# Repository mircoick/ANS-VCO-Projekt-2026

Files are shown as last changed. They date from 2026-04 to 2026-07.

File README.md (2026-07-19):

17.07.2026

<div align="center">

# VCO Design und Simulation

**Entwicklung und Inbetriebnahme eines Wien-Robinson-Oszillators als
Voltage-Controlled-Ozillator ($f_0=5,5~\text{MHz}$)**






<table style="border: none; border-collapse: collapse; margin: 0 auto;" border="0">

<tr style="border: none;">

<td style="border: none; padding: 0 25px; text-align: center;">

Tassilo Hertling


</td>

<td style="border: none; padding: 0 25px; text-align: center;">

Torben Becker


</td>

<td style="border: none; padding: 0 25px; text-align: center;">

Mirco Ick


</td>

</tr>

</table>

</br> </br>

**Dateiübersicht**

[KiCad-Dateien](kicad/) · [Simulationsdaten](sim/) · [Python
Code](code/) · [Datenblätter](datasheets/)

</div>

------------------------------------------------------------------------

# Einleitung

In diesem Projekt gilt es einen VCO (Voltage Controlled Oszillator) zu
designen und in Betrieb zu nehmen. Das Design soll bestimmte
Anforderungen erfüllen, damit es in einem Laborversuch als FM-Modulator
genutzt werden kann. In der Vergangenheit wurde im Laborversuch eine VCO
Schaltung mit alten und abgekündigkten Komponenten verwendet. Diese
Schaltung soll nun mit neuen und verfügbaren Komponenten erneuert
werden.

Die VCO Schaltung soll eine FM-Modulation mit einem Trägersignal bei der
Frequenz $5,5~\text{MHz}$ durchführen und einen Modulationsbereich
zwischen $5~\text{MHz}$ und $6~\text{MHz}$ verwenden. Der
Einstellungsbereich soll mit $1~\text{V}$ pro $1~\text{MHz}$ eingestellt
werden. Somit kann das zu modulierende Signal einen Spannungsbereich von
$V_{pp} = 1~\text{V}$ haben. Die Ein- und Ausgangsimpedanz soll
$50~\Omega$ betragen.

Zudem soll die Schaltung aus Komponenten bestehen, die Studierenden im
4.Semester bereits kennen, damit die Schaltung im Rahmen des
Laborversuchs im Grunde verstanden werden kann. Aus dieser
Rahmenbedingung folgt die Auswahl der spezifischen VCO-Schaltung.

Die Platine soll zudem relativ groß ausgelegt werden und es sollen
möglichst bedrahtete Bauteile verwendet werden. In dem Laborversuch soll
ebenfalls die Kennlinie des FM-Modulators aufgenommen werden. Hierfür
ist ein integrierter einstellbarer Spannungsteiler vorgesehen, der über
einen Drehregler auf der Platine eingestellt werden soll.

Die Schaltung soll ebenfalls Stabil gegenüber Schwankungen in der
Versorgungsspannung und somit in der Ausgangsfrequenz ausgelegt sein.
Anschlüsse für die im Laborversuch verwendeten Geräte wie das
Oszilloskop und dem Spektrumanalysator sollen über SMA- oder
BNC-Anschlüsse geschehen.

# Technische Spezifikationen (Kundenanforderungen)

- **Mittenfrequenz ($f_0$):** $5,5~\text{MHz}$ (Zwischenfrequenz / ZF)
  bei einer Steuerspannung von $0~\text{V}$.

- **Linearer Modulationsbereich:** $\pm 0,5~\text{MHz}$ (Frequenzhub)
  bei einer Steuerspannung von $\pm 0,5~\text{V}$.

  - *Arbeitsbereich:* $5,0~\text{MHz}$ bis $6,0~\text{MHz}$ linear im
    Spannungsbereich von $-0,5~\text{V}$ bis $+0,5~\text{V}$.

- **Frequenzstabilität:** Es darf keine Frequenzverschiebung (Drift)
  durch thermische oder externe Einflüsse auftreten.

- **Systemimpedanz:** Ein- und Ausgangswiderstand müssen exakt
  $50~\Omega$ betragen.

- **Steckverbinder:** Ein- und Ausgänge sind als **SMA-** oder
  **BNC-Buchsen** auszuführen.

- **Schaltungsarchitektur:** Einfacher, leicht zu verstehender und
  nachvollziehbarer Aufbau (diskreter Bauelemente).

- **Spannungsversorgung:** Integrierte Stabilisierung und Filterung der
  Versorgungsspannung zur Rauschunterdrückung.

- **Manuelle Steuerung:** Integrierter Spannungsteiler mit einem
  analogen Drehknopf (Potentiometer) zur Frequenzeinstellung.

- **Platinedesign:** Relativ große, robuste und mechanisch
  unempfindliche Leiterplatte.

- **Bestückungstechnologie:** Ausschließlich **stehende, bedrahtete
  Bauteile** für optimale Zugänglichkeit (keine SMD-Bauteile).

# Designverlauf

## Grundlegender VCO

Zuerst wurde im Design angefangen ein passendes VCO-Modell nach den
Anforderungen auszusuchen. Als Modell haben wurde sich für den LC-VCO
entschieden. Dieser besteht im Grunde aus einer RLC-Schaltung und einer
kreuzgekoppelten Mosfet-Schaltung. Das Design ist somit gut für
Studierende aus dem 4. Semester zu verstehen und kann auch gut mit
bedrahteten Bauteilen aufgebaut werden. Die Grundschaltung ist in
<a href="#fig-circuit" class="quarto-xref">Abbildung 1</a> zu sehen:

<div id="fig-circuit">

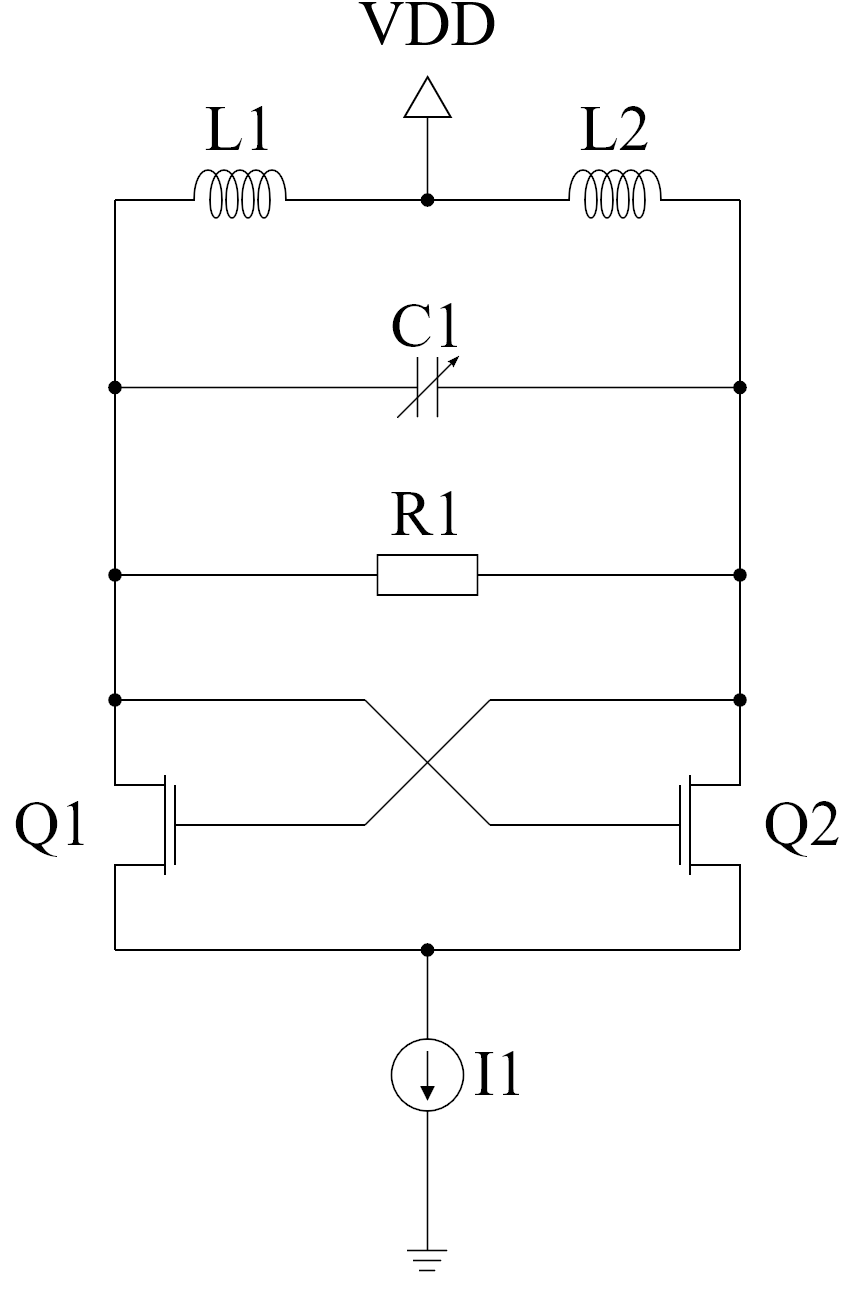
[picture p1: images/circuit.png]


Abbildung 1: VCO-Grundschaltung

</div>

In der Grundschaltung sind im oberen Bereich die beiden Induktivitäten
$L1$ und $L2$ in doppelter Ausführung zu sehen, da die
Versorgungsspannung mittig angeschlossen werden muss, um die Symmetrie
der Schaltung gewärleisten zu können. Weiter unten ist der einstellbare
Kondensator $C1$ zu sehen, dessen Wert die Schwingung der Schaltung
maßgeblich beeinflusst. Durch die Änderung des Kondensator ändert sich
auch die Frequenz $f_0$ der Schaltung. Somit kann duch eine gesteuerte
Änderung der Kapazität die Frequenz der Schwingung eingestellt werden.
Das ist das Grundprinzip des VCO´s und die Funktionsweise der
FM-Modulation. Der Widerstand $R1$ vervollständigt den RLC-Schwingkreis.
Die beiden kreugekoppelten Mosfets sind für die ständige Anregung der
Schwingung zuständig. Durch die ständige Änderung der gesamt Impedanz
des Schwingkreises ändert sich jeweils der Strom, der durch die Mosfets
am Gate Eingang anliegt. Diese Änderung bewirkt eine Rückgekoppelte
Schleife, durch welche schwingt das System dauerhaft. Nach
Implementierung dieser Schaltung in KiCad, NG- sowie LT-Spice konnte die
Funktionsweise sowie das Einstellen der Frequenz $f_0$ klarer gemacht
werden.

Im Verlauf der Entwicklung wurde sich entschieden verschiede VCO Ansätze
zu entwerfen und am Ende dem Kunden zu präsentieren. Unter den drei
Gruppen konnte sich neben dem Grund-VCO, welcher oben bereits erklärt
wurde, der Colpitts Oszillator oder der Wien-Robinson-Oszillator
ausgesucht werden. Da sich bereits im zweiten Semester ausgiebig mit der
Wien-Robinson Brücke auseinander gesetzt wurde haben wir uns für diesen
VCO entschieden, auf welchen in den nachfolgenden Kapiteln näher
eingegangen wird.

Eine Simulationsdatei ist dem Ordner
[VCO-Schwingkreis](kicad/Archiv/VCO-Schwingkreis/) zu entnehmen.

## Wien-Robinson-Oszillator

Um den Wien-Robinson-Oszillator besser verstehen zu können wurde sich
als erstes die Grundschaltung, die Wien-Robinson-Brücke, nochmals
angeschaut. Hierbei handelt es sich um eine frequenzabhängige
Wechselstrom-Messbrücke, die als sogenannte Nullbrücke konzipiert ist.
Das bedeutet, dass die Differenzspannung in der Brückendiagonale bei
einer spezifischen Resonanzfrequenz exakt
$\underset{\scriptscriptstyle\sim}{U} = 0~\text{V}$ beträgt. Ein
Schaltung ist der
<a href="#fig-wienrobbruecke" class="quarto-xref">Abbildung 2</a> zu
entnehmen.

<div id="fig-wienrobbruecke">

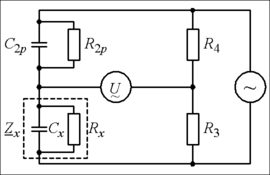
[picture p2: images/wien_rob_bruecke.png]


Abbildung 2: Wien-Robinson-Brücke
(<span class="nocase">de-academic.com</span> 2000-2026)

</div>

Wenn man nun an diese Brückendiagonale einen Operationsverstärker (OPV)
einbaut, erhält man einen aktiven Oszillator, der die
Frequenzselektivität der Brücke nutzt. Da der OPV die verschwindend
geringe Differenzspannung im Bereich der Resonanzfrequenz extrem hoch
verstärkt, reicht bereits das thermische Rauschen der Bauteile aus, um
das System resonant anzuregen. Somit erhält man einen sich selber
anwingenden Oszillator. Diese Wien-Robinson-Oszillator Schaltung ist
eine der meistgenutzen Schaltungen einer Wien-Robinson-Brücke und bietet
somit eine gute Grundlage des VCO’s. Für die ersten Tests mit dem
Wien-Robinson-Oszillator wurde die Seite des Elektroniktutors
herangezogen und versucht, die entsprechende Schaltung nachzustellen
(Mietke 2002-2026).

<div id="fig-wien">

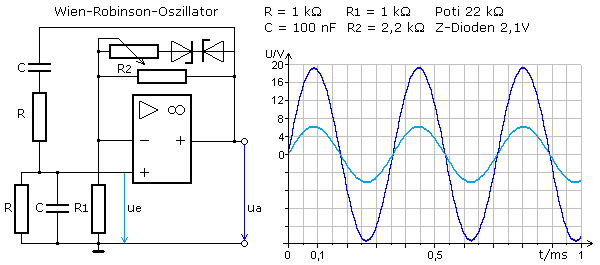
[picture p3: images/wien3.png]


Abbildung 3: Wien-Robinson-Oszillator Schaltung (Mietke 2002-2026)

</div>

Die in <a href="#fig-wien" class="quarto-xref">Abbildung 3</a> zu
sehende Schaltung zeigt wie bereits erörtert den in der
Brückendiagonalen eingebaute Operationsverstärker und eine zusätzliche
Amplitudenregulierung. Durch die starke Anregung der Schwingung des
OPV’s wurde hier noch eine Amplitudenregelung eingebaut, welche aus
einem Potentiometer und zwei entgegengeschalteten Varktordioden besteht.
Ohne diese Amplitudenregelung würde die Schwingung aufgrund der
unendlichen Verstärkung des OPV schnell bis an die Grenzen der
Versorgungsspannung anwachsen und begrenzen, was zu starken Verzerrungen
des Sinussignals führen würde. Die Regelung sorgt dafür, dass sich ein
stabiler, verzerrungsfreier Dauerschwingzustand einstellt.

Nachdem nun diese Schaltung erfolgreich in KiCAD, erst auf der
ursprünglichen Resonanzfrequenz $f_0=1592~\text{Hz}$ und anschließend
mit Änderung des OPV’s (LT7171) auf die gewünschten $5,5~\text{MHz}$,
umgesetzt wurde, konnte sich um den geforderten Frequenzhub von
$\Delta f=1~\text{MHz}$ bei einer Steuerspannungsänderung von
$U_{str}=\pm 0,5~\text{V}$ gemacht werden. Für den ersten Entwurf wurden
nun Varaktoren parallel zu den beiden Kondensatoren $C$ geschaltet.

Nach umsetzen dieser Schaltung haben sich jedoch zwei Probleme
kristallisiert. Zum einen kamen in den verschiedenen Simulationen (KiCAD
bzw. NG-Spice und LT-Spice) unterschiede Ergebnisse heraus, und zum
anderen war es nicht möglich die Kennlinie der Resonanzfrequenz $f_0$
über die Steuerspannung $U_{str}$ linear zu bekommen. Nach vielen
vergeblichen Versuchen wurde sich dann dazu entschieden den kompletten
Aufbau neu aufzusetzen und eine andere Schaltung zu verwenden.

## Wien-Robinson VCO

Die nachfolgende Schaltung in
<a href="#fig-wien-vco" class="quarto-xref">Abbildung 4</a> ist die
verwendete Schaltung für den Wie-Brücken-VCO. Am Anfang auf der linken
Seite ist die Verstärkerschaltung für die Steuerspannung der
Varaktordioden zu sehen. Diese soll die Einstellmöglichkeit für einen
Spannungsbereich zwischen $0~\text{V}$ und $1~\text{V}$ ermöglichen.
Diese Spannung geht über einen Widerstand auf die jeweiligen Kathoden
der Varaktordioden. Diese ändern ihre Kapazität in Abhängigkeit der
Steuerspannung. Der paralelle Kondensator ist hierbei für einen Offset
der Frequenz eingebaut worden und ist Teil der Wien-Brücke. Die Wien
Brücke ist in der Mitte der Schaltung zu sehen, bestehend aus insg. vier
Varaktordioden (D2-D5), zwei Kondensatoren (C1,C2) und zwei Widerständen
(R1,R2). Die Nachfolgende Verstärkerschaltung, bestehend aus U1, R3 und
R4 ist für die Verstärkung der Schwingung und aufrechterhaltung
zuständig. Die Verstärkung ist hier mit R3 und R4 auf Faktor 3
eingestellt. Die Amplitudenregelung zum Einschwingen der Schaltung ist
auf der unteren rechten Seite zu sehen. Diese besteht aus D1, C3, R5,
R7, R8 und J1. Diese Kombination regelt die Verstärkung am Anfang des
Einschwingverhalten höher als 3, damit die Schaltung in einen sicheren
Eingeschwungenen Zustand gerät. Sobald die Amplitude den eingestellten
Wert erreicht, regelt sich die Verstärkung automatisch über J1 wieder
auf 3 runter. Die Schaltung schwingt nun stabil.

<div id="fig-wien-vco">

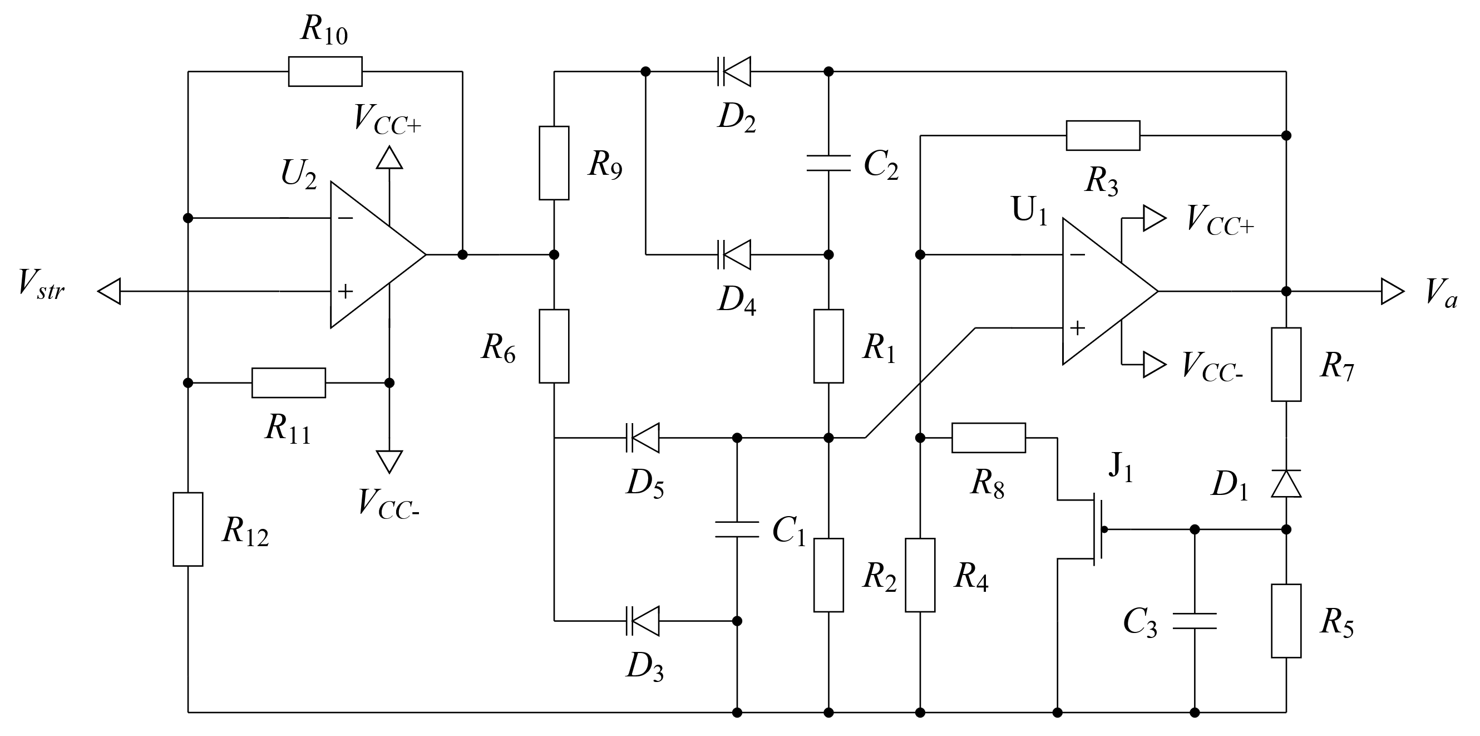
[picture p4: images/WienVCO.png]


Abbildung 4: Wien-Robinson-Oszillator VCO Schaltung (Geißler u. a. 1993)

</div>

Wir haben uns speziell für diese Schaltungsart entscheiden, da die
steuerbare Amplitudenregelung anfangs bessere Ergebnisse in der
Simulation mit NGSpice und LTSpice bezüglich der linearität der
Ausgangsfrequenz bessere Ergebnisse lieferte.

## Komponenten

Um den Wien-Robinson-Oszilator im gewünschten Frequenzbereich schwingen
zu lassen, musste die Grundschaltung angepasst werden und um
entsprechende Bauteile ersetzt werden.

### Operationsverstärker

Da die Schaltung maximal bei $6~\text{MHz}$ schwingen soll muss der OPV
sowohl ultra-high-speed sein als auch eine hohe Slew-rate haben.

### Varaktordioden

Damit die Mittenfrequenz verschoben werden kann, wurden varaktoren
Parrallel zu den Kondensatoren der Wien-Robinson-Brücke geschaltet. Um
sich in einem Lineraren Berreich zu bewegen müssen die Kennlinien der
Varaktoren in dem beschalteten Berreich auch linerar sein. Zudem müssen
diese eine möglichst hohe Änderung der Kapazität in diesem Berreich
vorweisen.

### Diode

Die Diode in der rückführenden Verstärkerschaltung des VCO´s muss
ebenfalls eine sehr schnelle Schottkydiode sein, da sie ebenfalls die
Signale von maximal $6~\text{MHz}$ sperren und durchlassen soll.

### Transistor

Der Transistor muss in diesem Fall ein J-FET, also ein Transistor,
welcher ohne Spannung maxiaml Leitend ist, eingebaut werden. Dieser wird
mit einer negativen Gleichspannung versorgt und muss somit nicht
High-Speed sein.

# Charakterisierung

Nachdem nun der Aufbau und die meisten Bauteile feststanden konnte sich
mit Hilfe von LTSpice eine Simulation des Aufbaus zusammengestellt
werden. Die Simulationsdateien können dem Ordner [sim](sim/) entnommen
werden.

## Bauteilauswahl der Varaktor-Diode

Die bereitgestellte [Varaktor-Dioden-Bibliothek](kicad\spicelibs)
umfasst 30 Einzelmodelle. Um eine Diode zu identifizieren, die eine
nahezu lineare Kapazitätsänderung von $\Delta C \approx 14~\text{pF}$
über einen Steuerspannungsbereich von $V_{str} = 3~\text{V}$ aufweist,
wurde ein Capometer eingesetzt. Dieses Capometer ermöglichte die
automatisierte Auswertung der Kennlinien, um die optimale Komponente für
die geplante Schaltung festzulegen. Es wird hier bei einer linear
ansteigenden Spannung die Kapazität der Diode in einer $C(V)$-Kennline
aufgetragen, wodurch der benötigte Kapaziätsunterschied direkt abgelesen
werden kann. Die LTSpice Schematic ist [hier](sim/capometer.asc)
zufinden.

Die Analyse der Modelle ergab, dass die
[BB535/SIE](datasheets/BB535.pdf) Varaktor Diode am besten zu den
Anforderungen passt. Somit wurden alle benötigten Bauteile gefunden und
die Silumation konnte durchgeführt werden.

## Simulation den Wien-Brücken-VCO’s

Um nun die Schaltung Simulieren zu können wurde LTSpice sowie auch
NGSpice über KiCAD zur Hilfe genommen. In beiden Fällen konnte der in
<a href="#fig-wien-vco" class="quarto-xref">Abbildung 4</a> zu sehende
Schaltungsaufbau genommen werden und mit den passenden Werten sowie
Bauteilen verknüpft werden. Das Simulationsergebnis der Schaltung
([KiCAD](kicad/Wien-VCO/)) Ausgewertet mit dem
[sim_plot.py](code/sim_plot.py) Skript ist der
<a href="#fig-sim-wien-vco" class="quarto-xref">Abbildung 5</a> zu
entnehmen. Für die LTSpice sowie NGSpice Bauteile wurden folgende Werte
festgelegt:

<div class="columns" style="display: flex; align-items: center;">

<div class="column" width="45%">

| Symbol | Bauteil | Typ / Wert | Model |
|:---|:---|:---|:---|
| **U1** | Operationsverstärker | MAX4104 |[MAX4104.lib](kicad/spicelibs/) |
| **U2** | Operationsverstärker | TL082 |  [elk.lib](kicad/spicelibs/) |
| **J1** | JFET | J113 | [J113.lib](kicad/spicelibs/) |
| **D1** | Diode | 1N6263 (Schottky) | [.model 1N6263](kicad/spicelibs/models.txt) |
| **D2-D5** | Kapazitätsdiode |  BB535/SIE  |  [.model BB535](kicad/spicelibs/models.txt)  |
| **C1-C2** | WRB Kondensator | $2{,}7~\text{pF}$ | |
| **C3** | Regelungs Kondensator | $2{,}0~\text{nF}$ | |
| **C4-C5** |$V_{str}$ Kondensator | $100~\text{nF}$ | |
| **R1-R2** | WRB Widerstand | $3{,}275~\text{k}\Omega$ | |
| **R3** | Verstärker Widerstand | $2{,}32~\text{k}\Omega$  | |
| **R4** | Verstärker Widerstand | $1{,}2~\text{k}\Omega$ | |
| **R5** | Regelungs Widerstand | $20~\text{k}\Omega$ | |
| **R6, R9**  | $V_{str}$ Widerstand | $100~\text{k}\Omega$ | |
| **R7** | Regelungs Widerstand | $1{,}0~\text{k}\Omega$ | |
| **R8** | Regelungs Widerstand | $8{,}0~\text{k}\Omega$ | |
| **R10** | $V_{str}$ Widerstand | $10~\text{k}\Omega$ | |
| **R11** | $V_{str}$ Widerstand | $75~\text{k}\Omega$ | |
| **R12** | $V_{str}$ Widerstand | $50~\text{k}\Omega$ | |

</div>

</div>

<div id="fig-sim-wien-vco">

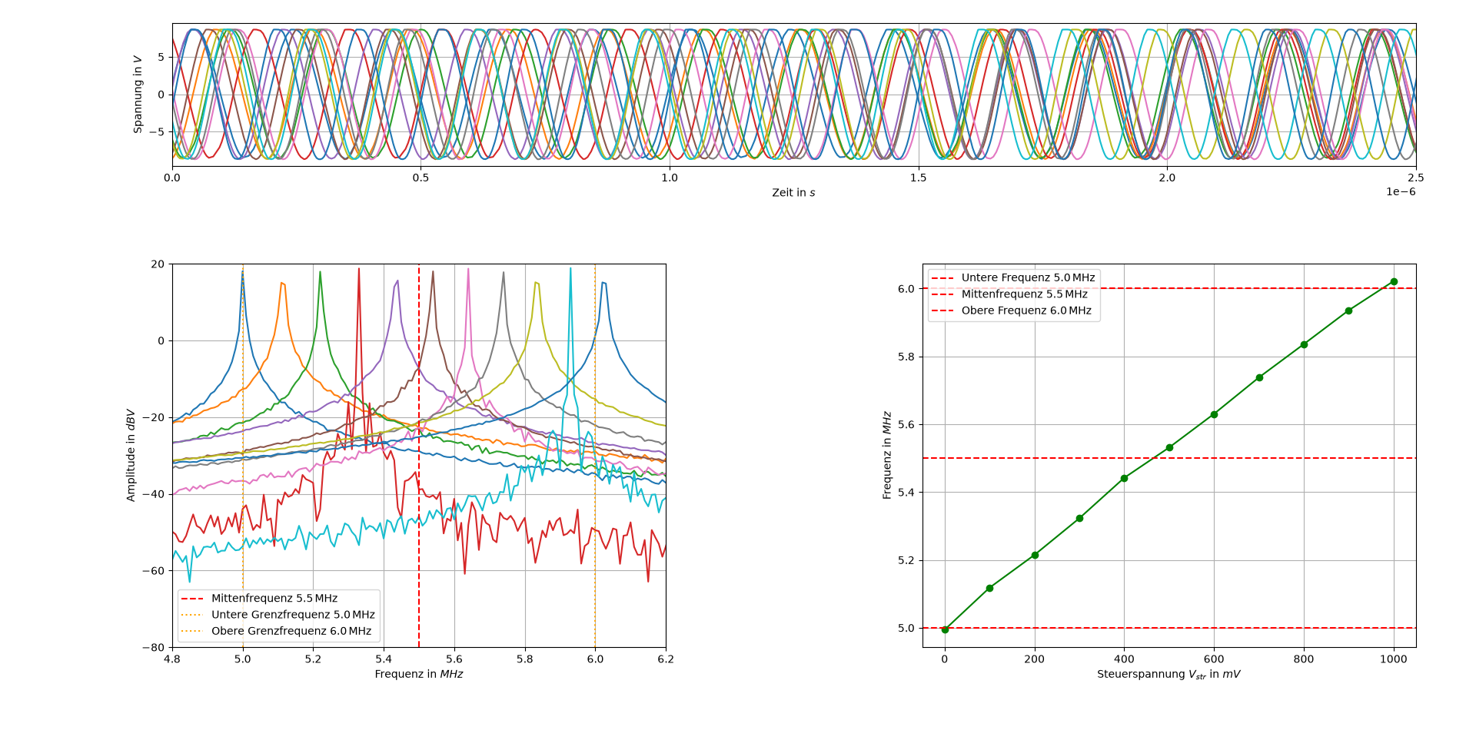
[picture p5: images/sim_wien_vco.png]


Abbildung 5: Simulationsergebnis mit Python Auswertung

</div>

Die in <a href="#fig-sim-wien-vco" class="quarto-xref">Abbildung 5</a>
dargestellte Simulation zeigt die vollständige Schaltung im
einstellbaren Steuerspannungsbereich von $V_{str} = 0 \dots 1~\text{V}$.
Die Auswertung umfasst drei Darstellungen:

Der obere Plot zeigt die Zeitsignale der 11 simulierten Zustände.
Hierbei lässt sich die Amplitudenstabilität der Schaltung überprüfen. Zu
sehen ist, dass die Amplitude über den gesamten Steuerspannungsbereich
sowohl im positiven als auch im negativen Bereich bei ca.
$\pm 9~\text{V}$ stabil bleibt. Die unterschiedlichen Frequenzen der
Signale sind bereits im Zeitbereich visuell erkennbar.

Um nun die Frequenzanteile genauer zu betrachten dient der untere linke
Plot, welcher die Fast Fourier Transformation (FFT) der Signale
visualisiert. Die Darstellung ermöglicht den Abgleich mit den
Kundenvorgaben für die Mittenfrequenz ($f_0 = 5,5~\text{MHz}$) sowie den
Grenzfrequenzen ($f_u = 5~\text{MHz}$ bis $f_o = 6~\text{MHz}$). Die
Analyse zeigt, dass bei einer Steuerspannung von $V_{str} = 0~\text{V}$
nahezu exakt $5~\text{MHz}$ erreicht werden. Die obere Grenzfrequenz
wird mit ca. $6,025~\text{MHz}$ nur minimal überschritten, was für eine
sehr gute Abstimmung der Schaltung spricht.

Der dritte Plot implimentiert die berechneten Peak-Frequenzen der FFT
mit der Steuerspannung. Im Idealfall entspräche die Kennlinie einer
Geraden, die exakt bei $(0~\text{V}, 5~\text{MHz})$ beginnt und bei
$(1~\text{V}, 6~\text{MHz})$ endet. Die Simulationsergebnisse bilden
diesen Verlauf sehr präzise ab. Die geringfügigen Abweichungen sind
primär auf die in LTspice bzw. NGspice hinterlegten Bauteiltoleranzen
sowie auf physikalisch notwendige Kompromisse bei der Bauteilwahl
zurückzuführen.

Zusammenfassend liegen die Simulationsergebnisse über den Erwartungen
und zeigen die Funktionalität sowie die gute Machbarkeit der zu
entwerfenden Wien-Brücken-VCO Platine.

## Fertige Platine

Im folgenden ist der Messaufbau zur Messwertaufnahme und
Charakterisierung der Schaltung zu sehen. Für die Spannungsversorgung
beider Operationsverstärker wurde enine Spannungsquelle verwendet,
welche auf $5~\text{V}$ eingestellt wurde. Die Spannung und somit die
Frequenz wurde mit einem PicoScope Oszilloskop aufgenommen.

<div id="fig-plat1">



Abbildung 6: Platine 1

</div>

Die beiden weiteren Bilder zeigen die bestückte Platine. Diese umfasst
die Wie-Robinson-Brücke mit den Varaktoren und der Verstärkerschaltung
des Oszillatorteils mit Ampltitudenregelung. Die Verstärkerschaltung der
Steuerspannung wurde auf dem Breadboard aufgebaut.

Die Platine wurde mit der, sich im kicad Ordner befindlichen
PDF-Dateien, belichtet und anschließend geätzt. Im Anschluss wurden alle
Löcher gebohrt und die Platine bestückt.

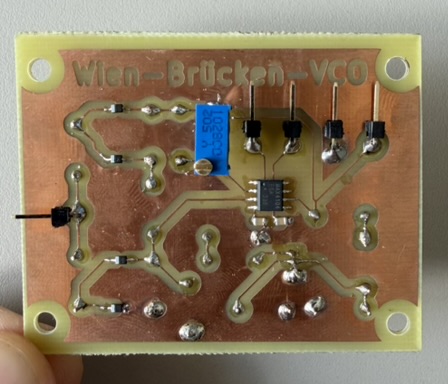
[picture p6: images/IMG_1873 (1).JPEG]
Platine 2

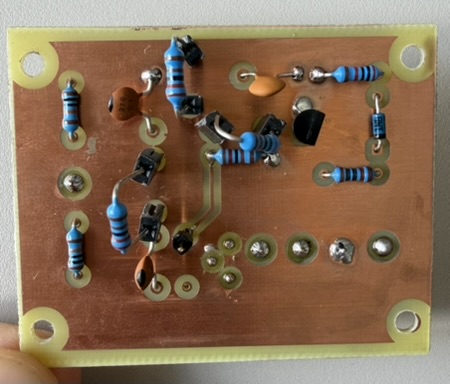
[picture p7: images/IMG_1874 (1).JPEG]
Platine 3


Aufgrund von parasitären Eigenschaften des Messaufbaus sowie des Platinenlayouts wichen die im realen Aufbau verwendeten Bauteilwerte von den ursprünglichen Simulationswerten ab. Diese Anpassungen waren notwendig, um die gewünschten Zielvorgaben und Spezifikationen zu erreichen. Die betroffenen Komponenten und ihre angepassten Werte sind in der folgenden Tabelle zusammengefasst:

<div class="columns" style="display: flex; align-items: center;">

<div class="column" width="45%">

| Symbol | Bauteil | Typ / Wert |
|:---|:---|:---|
| **C3** | Regelungs Kondensator | $1{,}0~\text{nF}$ |
| **R1-R2** | WRB Widerstand | $3{,}275~\text{k}\Omega$ |
| **R3** | Verstärker Widerstand | $2{,}32~\text{k}\Omega$  |
| **R4** | Verstärker Widerstand | $1{,}2~\text{k}\Omega$ |
| **R5** | Regelungs Widerstand | $20~\text{k}\Omega$ |
| **R6, R9**  | $V_{str}$ Widerstand | $100~\text{k}\Omega$ |
| **R7** | Regelungs Widerstand | $1{,}0~\text{k}\Omega$ |
| **R8** | Regelungs Widerstand | $8{,}0~\text{k}\Omega$ |
| **R10** | $V_{str}$ Widerstand | $10~\text{k}\Omega$ |
| **R11** | $V_{str}$ Widerstand | $75~\text{k}\Omega$ |
| **R12** | $V_{str}$ Widerstand | $50~\text{k}\Omega$ |

<div class="columns" style="display: flex; align-items: center;">

</div>

### Messergenisse

Im folgenden sind die Messergebnisse des zuvor gezeigten Messaufbaus zu
sehen.

<div id="fig-test">

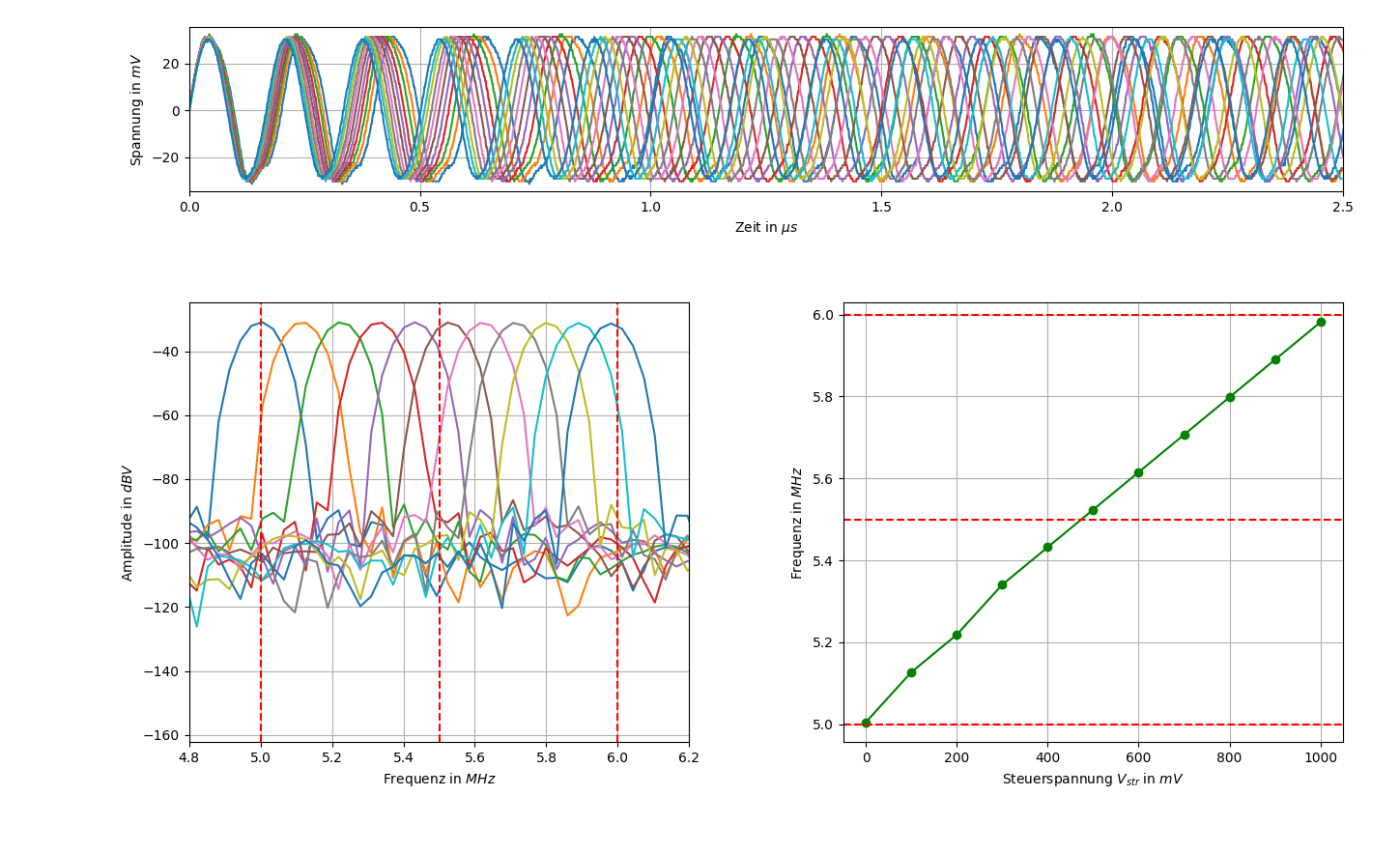
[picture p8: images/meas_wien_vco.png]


Abbildung 7: Darstellung der Messergebnisse mit Python

</div>

Das obere Diagramm zeigt die Spannung am Ausgang des VCOs. Diese bleibt
ebenfalls über den gesamten Steuerbereich konstant bei einer Amplitude
von etwa $\pm 35~\text{mV}$. Zudem ist eine leichte Verzerrung der
Schwingung zu erkennen, dies ist auf den Operationsverstärker und deren
Amplitudensteuerung zurückzuführen. Anhand des Spektrums sind ebenfalls
die Peaks im Bereich des benötigten Frequenzbereichs zu sehen. Diese
ordnen sich präzise zwischen den markierten Grenzfrequenzen von
$5,0~\text{MHz}$ und $6,0~\text{MHz}$ ein, wobei sich das Nutzsignal
bei etwa $-30~\text{dBV}$ mit einem hohen Störabstand deutlich vom
Grundrauschen abhebt. Die Kennlinie der Steuerspannung zu der
Ausgangsfrequenz zeigt ebenfalls ein deutliches lineares Verhalten, wie
bereits in der Simulation zu sehen. Der abgebildete Steuerbereich von
$0~\text{V}$ bis $1~\text{V}$ deckt den geforderten Frequenzhub
präzise ab, wobei die Kurve bei $0~\text{V}$ exakt bei
$5,0~\text{MHz}$ startet und bei $1~\text{V}$ den oberen Grenzwert von
$6,0~\text{MHz}$ erreicht

# Ordnerstruktur

``` {text}
.
├── code/
├── data/
├── datasheets/
├── images/
├── kicad/
│   ├── Archiv/
|       ├── VCO-Schwingkreis/
│   ├── footprints/
│   ├── spicelibs/
│   └── Wien-VCO/
├── report/
├── sim/
├── .gitignore
└── README.md
```

# Literaturverzeichnis

<div id="refs" class="references csl-bib-body hanging-indent">

<div id="ref-wienrobinsonbruecke" class="csl-entry">

<span class="nocase">de-academic.com</span>. 2000-2026.
*Wien-Robinson-Brücke*. Design Reference.
<https://de-academic.com/dic.nsf/dewiki/1507065>.

</div>

<div id="ref-geissler1993" class="csl-entry">

Geißler, Rainer, Werner Kammerloher, und Hans Werner Schneider. 1993.
*Berechnungs- und Entwurfsverfahren der Hochfrequenztechnik 1*.
Vieweg+Teubner Verlag Wiesbaden.
<https://doi.org/10.1007/978-3-322-84915-1>.

</div>

<div id="ref-wienbruecke" class="csl-entry">

Mietke, Detlef. 2002-2026. *Wien-Robinson-Oszillator*. Design Reference.
<https://www.elektroniktutor.de/signalkunde/wien_osz.html>.

</div>

</div>

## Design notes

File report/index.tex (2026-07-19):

% Options for packages loaded elsewhere
% Options for packages loaded elsewhere
\PassOptionsToPackage{unicode,linktoc=all}{hyperref}
\PassOptionsToPackage{hyphens}{url}
\PassOptionsToPackage{dvipsnames,svgnames,x11names}{xcolor}
%
\documentclass[
  ngerman,
  11pt,
  a4paper,
  DIV=11,
  twoside]{scrreprt}
\usepackage{xcolor}
\usepackage[inner=3cm,outer=4cm,top=3cm,bottom=4cm,headsep=22pt,headheight=11pt,footskip=33pt,ignorehead,ignorefoot,heightrounded]{geometry}
\usepackage{amsmath,amssymb}
\setcounter{secnumdepth}{2}
\usepackage{iftex}
\ifPDFTeX
  \usepackage[T1]{fontenc}
  \usepackage[utf8]{inputenc}
  \usepackage{textcomp} % provide euro and other symbols
\else % if luatex or xetex
  \usepackage{unicode-math} % this also loads fontspec
  \defaultfontfeatures{Scale=MatchLowercase}
  \defaultfontfeatures[\rmfamily]{Ligatures=TeX,Scale=1}
\fi
\usepackage{lmodern}
\ifPDFTeX\else
  % xetex/luatex font selection
  \setmainfont[]{Calibri}
  \setmathfont[]{TeX Gyre Termes Math}
\fi
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
\IfFileExists{footnotehyper.sty}{\usepackage{footnotehyper}}{\usepackage{footnote}}
\makesavenoteenv{longtable}
\usepackage{graphicx}
\makeatletter
\newsavebox\pandoc@box
\newcommand*\pandocbounded[1]{% scales image to fit in text height/width
  \sbox\pandoc@box{#1}%
  \Gscale@div\@tempa{\textheight}{\dimexpr\ht\pandoc@box+\dp\pandoc@box\relax}%
  \Gscale@div\@tempb{\linewidth}{\wd\pandoc@box}%
  \ifdim\@tempb\p@<\@tempa\p@\let\@tempa\@tempb\fi% select the smaller of both
  \ifdim\@tempa\p@<\p@\scalebox{\@tempa}{\usebox\pandoc@box}%
  \else\usebox{\pandoc@box}%
  \fi%
}
% Set default figure placement to htbp
\def\fps@figure{htbp}
\makeatother

% definitions for citeproc citations
\NewDocumentCommand\citeproctext{}{}
\NewDocumentCommand\citeproc{mm}{%
  \begingroup\def\citeproctext{#2}\cite{#1}\endgroup}
\makeatletter
 % allow citations to break across lines
 \let\@cite@ofmt\@firstofone
 % avoid brackets around text for \cite:
 \def\@biblabel#1{}
 \def\@cite#1#2{{#1\if@tempswa , #2\fi}}
\makeatother
\newlength{\cslhangindent}
\setlength{\cslhangindent}{1.5em}
\newlength{\csllabelwidth}
\setlength{\csllabelwidth}{3em}
\newenvironment{CSLReferences}[2] % #1 hanging-indent, #2 entry-spacing
 {\begin{list}{}{%
  \setlength{\itemindent}{0pt}
  \setlength{\leftmargin}{0pt}
  \setlength{\parsep}{0pt}
  % turn on hanging indent if param 1 is 1
  \ifodd #1
   \setlength{\leftmargin}{\cslhangindent}
   \setlength{\itemindent}{-1\cslhangindent}
  \fi
  % set entry spacing
  \setlength{\itemsep}{#2\baselineskip}}}
 {\end{list}}
\usepackage{calc}
\newcommand{\CSLBlock}[1]{\hfill\break\parbox[t]{\linewidth}{\strut\ignorespaces#1\strut}}
\newcommand{\CSLLeftMargin}[1]{\parbox[t]{\csllabelwidth}{\strut#1\strut}}
\newcommand{\CSLRightInline}[1]{\parbox[t]{\linewidth - \csllabelwidth}{\strut#1\strut}}
\newcommand{\CSLIndent}[1]{\hspace{\cslhangindent}#1}

\ifLuaTeX
\usepackage[bidi=basic,shorthands=off]{babel}
\else
\usepackage[bidi=default,shorthands=off]{babel}
\fi
\ifPDFTeX
\else
\babelfont{rm}[]{Calibri}
\fi
\ifLuaTeX
  \usepackage{selnolig} % disable illegal ligatures
\fi

\setlength{\emergencystretch}{3em} % prevent overfull lines

\providecommand{\tightlist}{%
  \setlength{\itemsep}{0pt}\setlength{\parskip}{0pt}}

\usepackage{circuitikz}
\usetikzlibrary{arrows.meta}
\KOMAoption{captions}{tableheading}
\makeatletter
\@ifpackageloaded{caption}{}{\usepackage{caption}}
\AtBeginDocument{%
\ifdefined\contentsname
  \renewcommand*\contentsname{Inhaltsverzeichnis}
\else
  \newcommand\contentsname{Inhaltsverzeichnis}
\fi
\ifdefined\listfigurename
  \renewcommand*\listfigurename{Abbildungsverzeichnis}
\else
  \newcommand\listfigurename{Abbildungsverzeichnis}
\fi
\ifdefined\listtablename
  \renewcommand*\listtablename{Tabellenverzeichnis}
\else
  \newcommand\listtablename{Tabellenverzeichnis}
\fi
\ifdefined\figurename
  \renewcommand*\figurename{Abbildung}
\else
  \newcommand\figurename{Abbildung}
\fi
\ifdefined\tablename
  \renewcommand*\tablename{Tabelle}
\else
  \newcommand\tablename{Tabelle}
\fi
}
\@ifpackageloaded{float}{}{\usepackage{float}}
\floatstyle{ruled}
\@ifundefined{c@chapter}{\newfloat{codelisting}{h}{lop}}{\newfloat{codelisting}{h}{lop}[chapter]}
\floatname{codelisting}{Listing}
\newcommand*\listoflistings{\listof{codelisting}{Listingverzeichnis}}
\makeatother
\makeatletter
\makeatother
\makeatletter
\@ifpackageloaded{caption}{}{\usepackage{caption}}
\@ifpackageloaded{subcaption}{}{\usepackage{subcaption}}
\makeatother
\usepackage{bookmark}
\IfFileExists{xurl.sty}{\usepackage{xurl}}{} % add URL line breaks if available
\urlstyle{same}
\hypersetup{
  pdftitle={VCO Design und Simulation},
  pdfauthor={Mirco Ick; Torben Becker; Tassilo Hertling},
  pdflang={de},
  colorlinks=true,
  linkcolor={blue},
  filecolor={Maroon},
  citecolor={Blue},
  urlcolor={Blue},
  pdfcreator={LaTeX via pandoc}}

\title{VCO Design und Simulation}
\author{Mirco Ick \and Torben Becker \and Tassilo Hertling}
\date{2026-07-02}
\begin{document}
\maketitle

\renewcommand*\contentsname{Inhaltsverzeichnis}
{
\setcounter{tocdepth}{2}
\tableofcontents
}

\chapter{Introduction}\label{introduction}

In diesesm Projekt gilt es einen VCO (Voltage Controlled Oszillator) zu
designen und in Betrieb zu nehmen. Das Design soll bestimmte
Anforderungen erfüllen, damit es in einem Laborversuch als FM-Modulator
genutzt werden kann. In der Vergangenheit wurde im Laborversuch eine VCO
Schaltung mit alten und abgekündigkten Komponenten verwendet. Diese
Schaltung soll nun mit neuen und verfügbaren Komponenten erneuert
werden.

Die VCO Schaltung soll eine FM-Modulation mit einem Trägersignal bei der
Frequenz \(5,5~\text{MHz}\) durchführen und einen Modulationsbereich
zwischen \(5~\text{MHz}\) und \(6~\text{MHz}\) verwenden. Der
Einstellungsbereich soll mit \(1~\text{V}\) pro \(1~\text{MHz}\)
eingestellt werden. Somit kann das zu modulierende Signal einen
Spannungsbereich von \(V_{pp} = 1~\text{V}\) haben. Die Ein- und
Ausgangsimpedanz soll \(50~\Omega\) betragen.

Zudem soll die Schaltung aus Komponenten bestehen, die Studierenden im
4.Semester bereits kennen, damit die Schaltung im Rahmen des
Laborversuchs im Grunde verstanden werden kann. Aus dieser
Rahmenbedingung folgt die Auswahl der spezifischen VCO-Schaltung.

Die Platine soll zudem relativ groß ausgelegt werden und es sollen
möglichst bedrahtete Bauteile verwendet werden. In dem Laborversuch soll
ebenfalls die Kennlinie des FM-Modulators aufgenommen werden. Hierfür
ist ein integrierter einstellbarer Spannungsteiler vorgesehen, der über
einen Drehregler auf der Platine eingestellt werden soll.

Die Schaltung soll ebenfalls Stabil gegenüber Schwankungen in der
Versorgungsspannung und somit in der Ausgangsfrequenz ausgelegt sein.
Anschlüsse für die im Laborversuch verwendeten Geräte wie das
Oszilloskop und dem Spektrumanalysator sollen über SMA- oder
BNC-Anschlüsse geschehen.

\chapter{Technische Spezifikationen
(Kundenanforderungen)}\label{technische-spezifikationen-kundenanforderungen}

\begin{itemize}
\item
  \textbf{Mittenfrequenz (\(f_0\)):} \(5,5~\text{MHz}\)
  (Zwischenfrequenz / ZF) bei einer Steuerspannung von \(0~\text{V}\).
\item
  \textbf{Linearer Modulationsbereich:} \(\pm 0,5~\text{MHz}\)
  (Frequenzhub) bei einer Steuerspannung von \(\pm 0,5~\text{V}\).

  \begin{itemize}
  \tightlist
  \item
    \emph{Arbeitsbereich:} \(5,0~\text{MHz}\) bis \(6,0~\text{MHz}\)
    linear im Spannungsbereich von \(-0,5~\text{V}\) bis
    \(+0,5~\text{V}\).
  \end{itemize}
\item
  \textbf{Frequenzstabilität:} Es darf keine Frequenzverschiebung
  (Drift) durch thermische oder externe Einflüsse auftreten.
\item
  \textbf{Systemimpedanz:} Ein- und Ausgangswiderstand müssen exakt
  \(50~\Omega\) betragen.
\item
  \textbf{Steckverbinder:} Ein- und Ausgänge sind als \textbf{SMA-} oder
  \textbf{BNC-Buchsen} auszuführen.
\item
  \textbf{Schaltungsarchitektur:} Einfacher, leicht zu verstehender und
  nachvollziehbarer Aufbau (diskreter Bauelemente).
\item
  \textbf{Spannungsversorgung:} Integrierte Stabilisierung und Filterung
  der Versorgungsspannung zur Rauschunterdrückung.
\item
  \textbf{Manuelle Steuerung:} Integrierter Spannungsteiler mit einem
  analogen Drehknopf (Potentiometer) zur Frequenzeinstellung.
\item
  \textbf{Platinedesign:} Relativ große, robuste und mechanisch
  unempfindliche Leiterplatte.
\item
  \textbf{Bestückungstechnologie:} Ausschließlich \textbf{stehende,
  bedrahtete Bauteile} für optimale Zugänglichkeit (keine SMD-Bauteile).
\end{itemize}

\chapter{Designverlauf}\label{designverlauf}

\section{Grundlegender VCO}\label{grundlegender-vco}

Zuerst wurde im Design angefangen ein passendes VCO-Modell nach den
Anforderungen auszusuchen. Als Modell haben wurde sich für den LC-VCO
entschieden. Dieser besteht im Grunde aus einer RLC-Schaltung und einer
kreuzgekoppelten Mosfet-Schaltung. Das Design ist somit gut für
Studierende aus dem 4. Semester zu verstehen und kann auch gut mit
bedrahteten Bauteilen aufgebaut werden. Die Grundschaltung ist in
Abbildung~\ref{fig-circuit} zu sehen:

\begin{figure}

\centering{



}

\caption{\label{fig-circuit}VCO-Grundschaltung}

\end{figure}%

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

Im Verlauf der Entwicklung wurde sich entschieden verschiede VCO Ansätze
zu entwerfen und am Ende dem Kunden zu präsentieren. Unter den drei
Gruppen konnte sich neben dem Grund-VCO, welcher oben bereits erklärt
wurde, der Colpitts Oszillator oder der Wien-Robinson-Oszillator
ausgesucht werden. Da sich bereits im zweiten Semester ausgiebig mit der
Wien-Robinson Brücke auseinander gesetzt wurde haben wir uns für diesen
VCO entschieden, auf welchen in den nachfolgenden Kapiteln näher
eingegangen wird.

Eine Simulationsdatei ist dem Ordner
\href{./kicad/Archiv/VCO-Schwingkreis/}{VCO-Schwingkreis} zu entnehmen.

\section{Wien-Robinson-Oszillator}\label{wien-robinson-oszillator}

Um den Wien-Robinson-Oszillator besser verstehen zu können wurde sich
als erstes die Grundschaltung, die Wien-Robinson-Brücke, nochmals
angeschaut. Hierbei handelt es sich um eine frequenzabhängige
Wechselstrom-Messbrücke, die als sogenannte Nullbrücke konzipiert ist.
Das bedeutet, dass die Differenzspannung in der Brückendiagonale bei
einer spezifischen Resonanzfrequenz exakt
\(\underset{\scriptscriptstyle\sim}{U} = 0~\text{V}\) beträgt. Ein
Schaltung ist der Abbildung~\ref{fig-wienrobbruecke} zu entnehmen.

\begin{figure}

\centering{



}

\caption{\label{fig-wienrobbruecke}Wien-Robinson-Brücke
({de-academic.com} 2000-2026)}

\end{figure}%

Wenn man nun an diese Brückendiagonale einen Operationsverstärker (OPV)
einbaut, erhält man einen aktiven Oszillator, der die
Frequenzselektivität der Brücke nutzt. Da der OPV die verschwindend
geringe Differenzspannung im Bereich der Resonanzfrequenz extrem hoch
verstärkt, reicht bereits das thermische Rauschen der Bauteile aus, um
das System resonant anzuregen. Somit erhält man einen sich selber
anwingenden Oszillator. Diese Wien-Robinson-Oszillator Schaltung ist
eine der meistgenutzen Schaltungen einer Wien-Robinson-Brücke und bietet
somit eine gute Grundlage des VCO's. Für die ersten Tests mit dem
Wien-Robinson-Oszillator wurde die Seite des Elektroniktutors
herangezogen und versucht, die entsprechende Schaltung nachzustellen
(Mietke 2002-2026).

\begin{figure}

\centering{



}

\caption{\label{fig-wien}Wien-Robinson-Oszillator Schaltung (Mietke
2002-2026)}

\end{figure}%

Die in Abbildung~\ref{fig-wien} zu sehende Schaltung zeigt wie bereits
erörtert den in der Brückendiagonalen eingebaute Operationsverstärker
und eine zusätzliche Amplitudenregulierung. Durch die starke Anregung
der Schwingung des OPV's wurde hier noch eine Amplitudenregelung
eingebaut, welche aus einem Potentiometer und zwei entgegengeschalteten
Varktordioden besteht. Ohne diese Amplitudenregelung würde die
Schwingung aufgrund der unendlichen Verstärkung des OPV schnell bis an
die Grenzen der Versorgungsspannung anwachsen und begrenzen, was zu
starken Verzerrungen des Sinussignals führen würde. Die Regelung sorgt
dafür, dass sich ein stabiler, verzerrungsfreier Dauerschwingzustand
einstellt.

Nachdem nun diese Schaltung erfolgreich in KiCAD, erst auf der
ursprünglichen Resonanzfrequenz \(f_0=1592~\text{Hz}\) und anschließend
mit Änderung des OPV's (LT7171) auf die gewünschten \(5,5~\text{MHz}\),
umgesetzt wurde, konnte sich um den geforderten Frequenzhub von
\(\Delta f=1~\text{MHz}\) bei einer Steuerspannungsänderung von
\(U_{str}=\pm 0,5~\text{V}\) gemacht werden. Für den ersten Entwurf
wurden nun Varaktoren parallel zu den beiden Kondensatoren \(C\)
geschaltet. Ein erster Versuch ist der \textbf{?@fig-wienvarak} zu
entnehemen.

\textbf{Abbildung mit Wien-Robinson-Oszillator mit Frequenzhub}

Nach umsetzen dieser Schaltung haben sich jedoch zwei Probleme
kristallisiert. Zum einen kamen in den verschiedenen Simulationen (KiCAD
bzw. NG-Spice und LT-Spice) unterschiede Ergebnisse heraus, und zum
anderen war es nicht möglich die Kennlinie der Resonanzfrequenz \(f_0\)
über die Steuerspannung \(U_{str}\) linear zu bekommen. Nach vielen
vergeblichen Versuchen wurde sich dann dazu entschieden den kompletten
Aufbau neu aufzusetzen und eine andere Schaltung zu verwenden.

\section{Wien-Robinson VCO}\label{wien-robinson-vco}

\section{Komponenten}\label{komponenten}

Um den Wien-Robinson-Oszilator im gewünschten Berreich zu bekommen
musste die Grundschaltung angepasst werden und entsprechende Bauteile
rausgesucht werden.

\subsection{Operationsverstärker}\label{operationsverstuxe4rker}

Da die Schaltung um \(5~\text{MHz}\) schwingen soll muss der OPV sowohl
ultra-high-speed sein als auch eine hohe Slew-rate haben.

\subsection{Varaktoren}\label{varaktoren}

Damit die Mittenfrequenz verschoben werden kann wurden varaktoren
Parrallel zu den Kondensatoren der Wien-Robinson-Brücke geschaltet. Um
sich in einem Lineraren Berreich zu bewegen müssen die kennlinien der
varaktoren in dem beschalteten Berreich auch linerar sein. Zudem müssen
sie eine Möglichst hohe änderung der Kapazität in diesem Berreich haben.

\subsection{Diode}\label{diode}

?

\subsection{Diode}\label{diode}

\chapter{Charakterisierung}\label{charakterisierung}

\chapter*{Literaturverzeichnis}\label{literaturverzeichnis}
\addcontentsline{toc}{chapter}{Literaturverzeichnis}

\protect\phantomsection\label{refs}
\begin{CSLReferences}{1}{1}
\bibitem[\citeproctext]{ref-wienrobinsonbruecke}
{de-academic.com}. 2000-2026. \emph{Wien-Robinson-Brücke}. Design
Reference. \url{https://de-academic.com/dic.nsf/dewiki/1507065}.

\bibitem[\citeproctext]{ref-wienbruecke}
Mietke, Detlef. 2002-2026. \emph{Wien-Robinson-Oszillator}. Design
Reference.
\url{https://www.elektroniktutor.de/signalkunde/wien_osz.html}.

\end{CSLReferences}

\end{document}

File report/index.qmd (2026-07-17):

---
keyword:
  - VCO

date: last-modified
date-format: "DD.MM.YYYY"
number-sections: true
bibliography: references.bib
---

<div align="center">

# VCO Design und Simulation

**Entwicklung und Inbetriebnahme eines Wien-Robinson-Oszillators als Voltage-Controlled-Ozillator ($f_0=5,5~\text{MHz}$)**






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

</br>
</br>

**Dateiübersicht**

[KiCad-Dateien](kicad/) · [Simulationsdaten](sim/) · [Python Code](code/) · [Datenblätter](datasheets/)

</div>

---

{{< include content/_sec_introduction.qmd >}}
{{< include content/_sec_requirements.qmd >}}
{{< include content/_sec_designverlauf.qmd >}}
{{< include content/_sec_characterisation.qmd >}}
{{< include content/_sec_tree.qmd >}}
{{< include content/references.qmd >}}

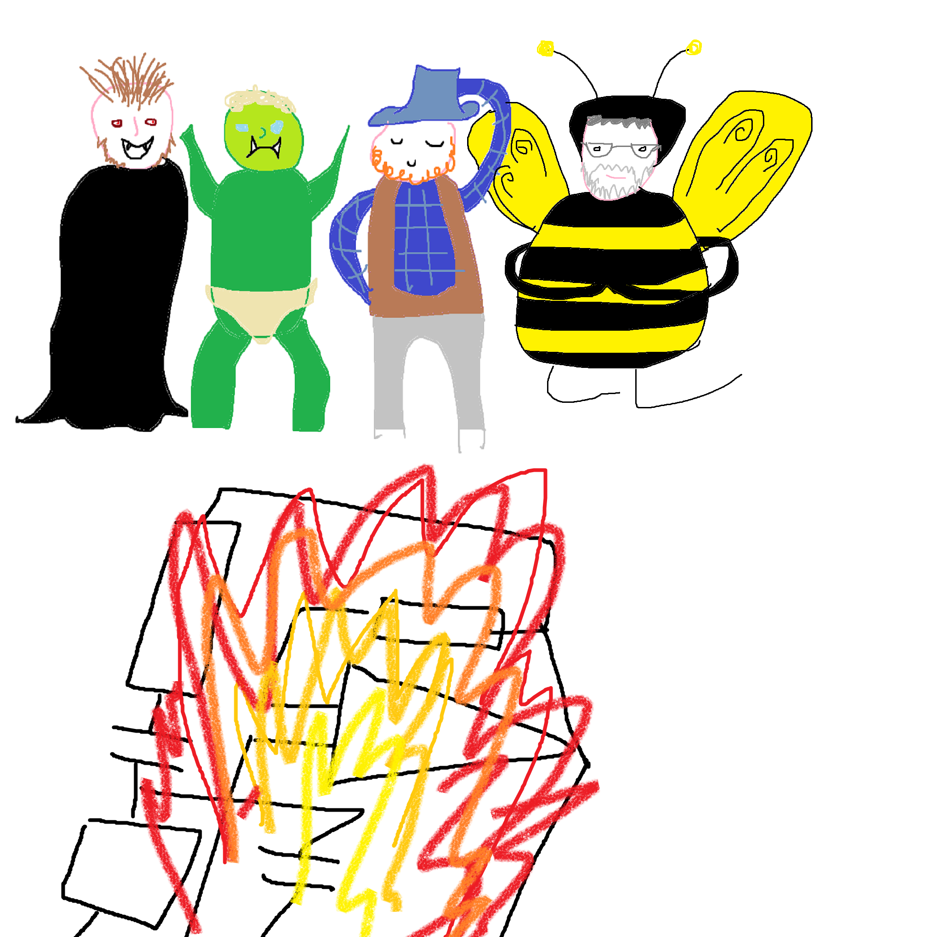
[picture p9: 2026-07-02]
report/images/Untitled.png

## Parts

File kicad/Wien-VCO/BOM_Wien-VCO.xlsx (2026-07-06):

 |  |  | BOM_Wien-LT_TB
Item # | *Designator | *Qty | Manufacturer | *Mfg Part # | Description / Value | *Package/Footprint | Type | Your Instructions / Notes
1 | U1 | 1 | Maxim | MAX4104ESA (https://www.rf-microwave.com/de/maxim/max4104esa/rauscharmer-operationsverstarker-mit-geringer-verzerrung/max4104esa/) | MAX4104ESA - Rauscharmer Operationsverstärker mit geringer Verzerrung, SMD SOIC-8 | SOIC 8 | SMD
2 | D1 | 1 | Generic | 1N6263 (https://de.farnell.com/stmicroelectronics/1n6263/hf-diode-schottky/dp/9801251) |  | DO-7 | THD
3 | J1 | 1 | ON Semiconductor | J113 (https://de.farnell.com/on-semiconductor/j113/transistor-jfet-n-to-92/dp/1017713) |  | TO−92 | THD
4 | U2 | 0 | Texas Instruments | TL082CD (https://www.rf-microwave.com/de/texas-instruments/tl082cd/dualer-jfet-operationsverstarker/tl082cd/) | TL082CD - Dualer JFET-Operationsverstärker, SMD SOIC-8 | SOIC 8 | SMD | Den wird es wohl schon geben im Labor
5 | D2,D3,D4,D5 | 4 | Infineon | BB535 (https://www.rf-microwave.com/de/philips/bb909a/varicap-diode-30-v-20-ma-2-6-31-pf-do-34/bb909a/) | Infineon Technologies Kapazitäts-Diode BB535 30 V 20 mA Einzeln SOD-323 Tape cut | SO-34 | THD
6 | C… | 0 | Stettner | CVC-06 (https://www.rf-microwave.com/de/stettner/300-330-405/drehkondensator-trimmer-4-20-pf-250v/cvc-06/) | 300.330.405 - Drehkondensator / Trimmer 4 - 20 pF, 250V | Radial | THD | Bauteil gibt es in LTSpice nicht aber es könnte für die Einstellung der Kondensatoren C1 und C2 verwendet werden
7 | U1_adapter, U2_adapter | 2 | - | LCQT-SOIC8-8 (https://de.farnell.com/aries/lcqt-soic8-8/ic-adapter-8-soic-dip-2-54mm/dp/2476033) | Adapter von SOIC8 auf THD RM2,54 mm | - | THD | Wenn U2 ggf. als THD Version vorhanden muss hier keine Adapterplatine verwendet werden
8 |  | 2 |  | LT1363CN8 (https://de.farnell.com/analog-devices/lt1363cn8-pbf/op-verst-rk-70mhz-40-bis-85-c/dp/4020651) | LT1363 | DIP |  | Farnell
9 |  | 2 |  | MAX4104ESA (https://de.farnell.com/analog-devices/max4104esa/op-verst-rker-625mhz-400v-us-nsoic/dp/2510842) |  |  |  | Farnell
10 |  | 2 |  | LM7171 (https://www.ti.com/product/LM7171) |  |  |  | TI
Hinweise: Die restlichen Widerstände und Kondensatoren sind Standard Bauteile und sollten somit vorhanden sein. Das gilt auch für den TL082

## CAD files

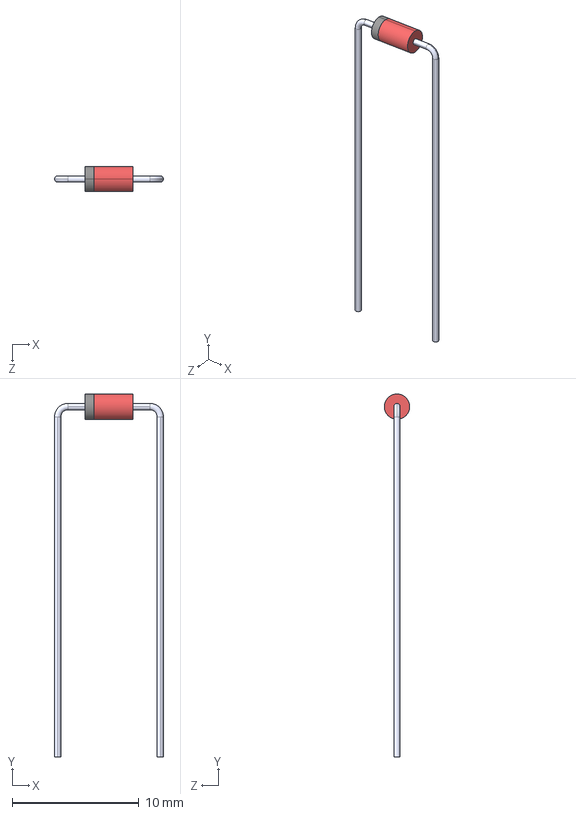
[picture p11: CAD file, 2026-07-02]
kicad/footprints/1N6263.STEP
8.60 x 28.7 x 2.00 mm

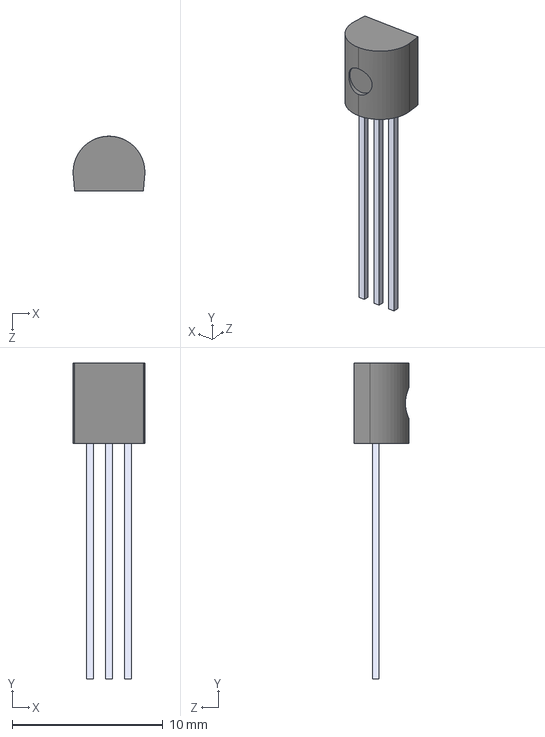
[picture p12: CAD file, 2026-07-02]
kicad/footprints/J113.STEP
4.76 x 21.0 x 3.62 mm

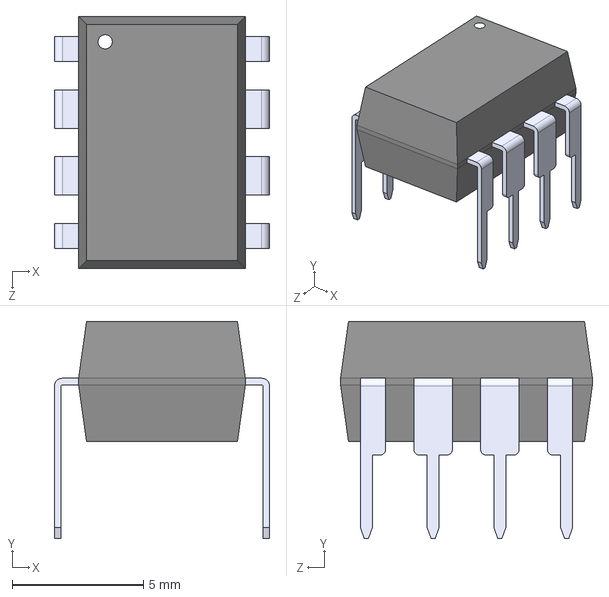
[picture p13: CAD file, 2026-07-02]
kicad/footprints/TL082CP.STEP
8.19 x 8.26 x 9.59 mm

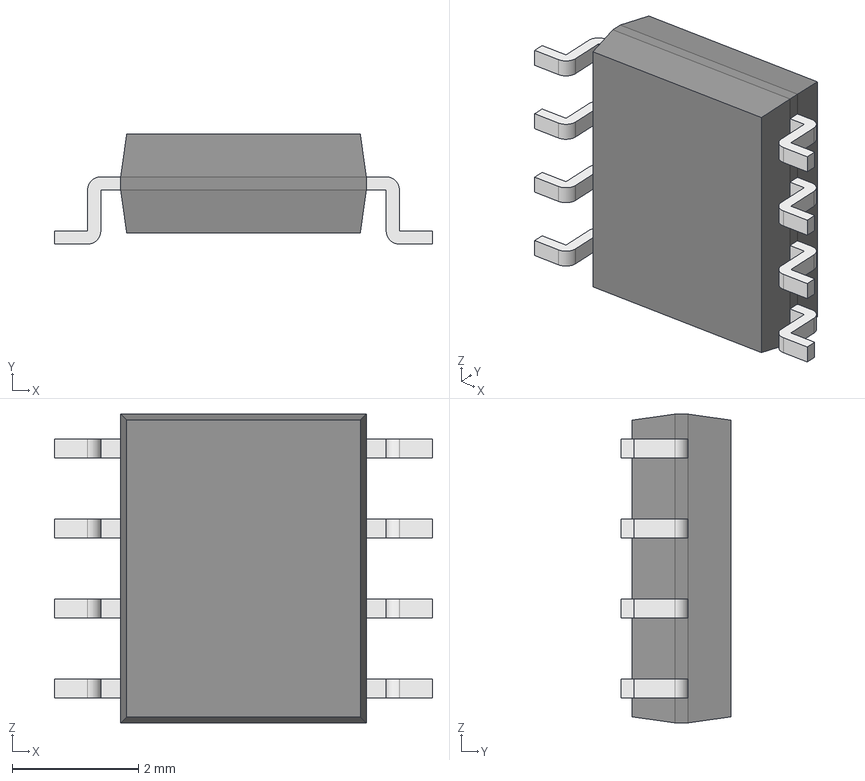
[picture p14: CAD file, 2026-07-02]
kicad/footprints/MAX4104ESA+.STEP
6.00 x 1.75 x 4.90 mm
Body001 (Mirror #1) x 4
XY-plane x 12
X-axis x 12

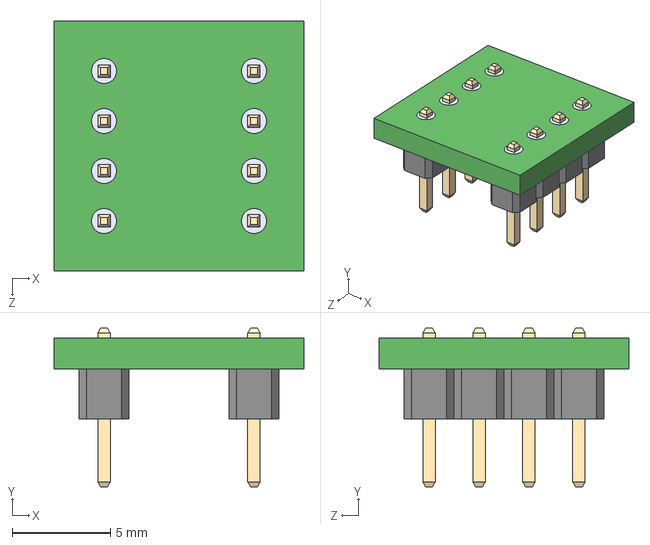
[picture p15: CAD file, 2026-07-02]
kicad/footprints/LCQT-SOIC8-8--3DModel-STEP-269445.STEP
12.7 x 8.08 x 12.7 mm

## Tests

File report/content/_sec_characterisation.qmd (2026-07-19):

# Charakterisierung
Nachdem nun der Aufbau und die meisten Bauteile feststanden konnte sich mit Hilfe von LTSpice eine Simulation des Aufbaus zusammengestellt werden. Die Simulationsdateien können dem Ordner [sim](sim/) entnommen werden. 

## Bauteilauswahl der Varaktor-Diode

Die bereitgestellte [Varaktor-Dioden-Bibliothek](kicad\spicelibs) umfasst 30 Einzelmodelle. Um eine Diode zu identifizieren, die eine nahezu lineare Kapazitätsänderung von $\Delta C \approx 14~\text{pF}$ über einen Steuerspannungsbereich von $V_{str} = 3~\text{V}$ aufweist, wurde ein Capometer eingesetzt. Dieses Capometer ermöglichte die automatisierte Auswertung der Kennlinien, um die optimale Komponente für die geplante Schaltung festzulegen. Es wird hier bei einer linear ansteigenden Spannung die Kapazität der Diode in einer $C(V)$-Kennline aufgetragen, wodurch der benötigte Kapaziätsunterschied direkt abgelesen werden kann. Die LTSpice Schematic ist [hier](sim/capometer.asc) zufinden.

Die Analyse der Modelle ergab, dass die [BB535/SIE](datasheets/BB535.pdf) Varaktor Diode am besten zu den Anforderungen passt. Somit wurden alle benötigten Bauteile gefunden und die Silumation konnte durchgeführt werden.

## Simulation den Wien-Brücken-VCO's

Um nun die Schaltung Simulieren zu können wurde LTSpice sowie auch NGSpice über KiCAD zur Hilfe genommen. In beiden Fällen konnte der in @fig-wien-vco zu sehende Schaltungsaufbau genommen werden und mit den passenden Werten sowie Bauteilen verknüpft werden. Das Simulationsergebnis der Schaltung ([KiCAD](kicad/Wien-VCO/)) Ausgewertet mit dem [sim_plot.py](code/sim_plot.py) Skript ist der @fig-sim-wien-vco zu entnehmen. Für die LTSpice sowie NGSpice Bauteile wurden folgende Werte festgelegt:

:::: {.columns style="display: flex; align-items: center;"}

::: {.column width="45%"}
| Symbol | Bauteil | Typ / Wert |
|:---|:---|:---|

| **U1**      | Operationsverstärker | MAX4104 |
| **U2**      | Operationsverstärker | TL082 |
| **J1**      | JFET | J113 |
| **D1**      | Diode | 1N6263 (Schottky) |
| **D2-D5**   | Kapazitätsdiode |  BB535/SIE  |
| **C1-C2**   | WRB Kondensator | $2{,}7~\text{pF}$   |
| **C3**      | Regelungs Kondensator | $2{,}0~\text{nF}$   |
| **C4-C5**   | V_{str} Kondensator | $100~\text{nF}$     |
| **R1-R2**   | WRB Widerstand | $3{,}275~\text{k}\Omega$ |
| **R3**      | Verstärker Widerstand | $2{,}32~\text{k}\Omega$  |
| **R4**      | Verstärker Widerstand | $1{,}2~\text{k}\Omega$   |
| **R5**      | Regelungs Widerstand | $20~\text{k}\Omega$      |
| **R6, R9**  | V_{str} Widerstand | $100~\text{k}\Omega$     |
| **R7**      | Regelungs Widerstand | $1{,}0~\text{k}\Omega$   |
| **R8**      | Regelungs Widerstand | $8{,}0~\text{k}\Omega$   |
| **R10**     | V_{str} Widerstand | $10~\text{k}\Omega$      |
| **R11**     | V_{str} Widerstand | $75~\text{k}\Omega$      |
| **R12**     | V_{str} Widerstand | $50~\text{k}\Omega$      |
:::

::::

Simulationsergebnis mit Python Auswertung

Die in @fig-sim-wien-vco dargestellte Simulation zeigt die vollständige Schaltung im einstellbaren Steuerspannungsbereich von $V_{str} = 0 \dots 1~\text{V}$. Sie wurde mit $VCC+ = +10~\text{V}$ und $VCC- = +10~\text{V}$ angesteuert. Die Auswertung umfasst drei Darstellungen:

Der obere Plot zeigt die Zeitsignale der 11 simulierten Zustände. Hierbei lässt sich die Amplitudenstabilität der Schaltung überprüfen. Zu sehen ist, dass die Amplitude über den gesamten Steuerspannungsbereich sowohl im positiven als auch im negativen Bereich bei ca. $\pm 9~\text{V}$ stabil bleibt. Die unterschiedlichen Frequenzen der Signale sind bereits im Zeitbereich visuell erkennbar. 

Um nun die Frequenzanteile genauer zu betrachten dient der untere linke Plot, welcher die Fast Fourier Transformation (FFT) der Signale visualisiert. Die Darstellung ermöglicht den Abgleich mit den Kundenvorgaben für die Mittenfrequenz ($f_0 = 5,5~\text{MHz}$) sowie den Grenzfrequenzen ($f_u = 5~\text{MHz}$ bis $f_o = 6~\text{MHz}$). Die Analyse zeigt, dass bei einer Steuerspannung von $V_{str} = 0~\text{V}$ nahezu exakt $5~\text{MHz}$ erreicht werden. Die obere Grenzfrequenz wird mit ca. $6,025~\text{MHz}$ nur minimal überschritten, was für eine sehr gute Abstimmung der Schaltung spricht.

Der dritte Plot implimentiert die berechneten Peak-Frequenzen der FFT mit der Steuerspannung. Im Idealfall entspräche die Kennlinie einer Geraden, die exakt bei $(0~\text{V}, 5~\text{MHz})$ beginnt und bei $(1~\text{V}, 6~\text{MHz})$ endet. Die Simulationsergebnisse bilden diesen Verlauf sehr präzise ab. Die geringfügigen Abweichungen sind primär auf die in LTspice bzw. NGspice hinterlegten Bauteiltoleranzen sowie auf physikalisch notwendige Kompromisse bei der Bauteilwahl zurückzuführen.

Zusammenfassend liegen die Simulationsergebnisse über den Erwartungen und zeigen die Funktionalität sowie die gute Machbarkeit der zu entwerfenden Wien-Brücken-VCO Platine.

## Fertige Platine

Im folgenden ist der Messaufbau zur Messwertaufnahme und Charakterisierung der Schaltung zu sehen. Für die Spannungsversorgung beider Operationsverstärker wurde enine Spannungsquelle verwendet, welche auf $5\,\text{V}$ eingestellt wurde. Die Spannung und somit die Frequenz wurde mit einem PicoScope Oszilloskop aufgenommen.

Platine 1

Die beiden weiteren Bilder zeigen die bestückte Platine. Diese umfasst die Wie-Robinson-Brücke mit den Varaktoren und der Verstärkerschaltung des Oszillatorteils mit Ampltitudenregelung. Die Verstärkerschaltung der Steuerspannung wurde auf dem Breadboard aufgebaut.

Die Platine wurde mit der, sich im kicad Ordner befindlichen PDF-Dateien, belichtet und anschließend geätzt. Im Anschluss wurden alle Löcher gebohrt und die Platine bestückt.

Platine 2
Platine 3

### Messergenisse

Im folgenden sind die Messergebnisse des zuvor gezeigten Messaufbaus zu sehen.

Darstellung der Messergebnisse mit Python

Das obere Diagramm zeigt die Spannung am Ausgang des VCOs. Diese bleibt ebenfalls über den gesamten Steuerbereich konstant bei einer Amplitude von etwa $\pm 25\,\text{mV}$. Zudem ist eine leichte Verzerrung der Schwingung zu erkennen, dies ist auf den Operationsverstärker und deren Amplitudensteuerung zurückzuführen. Anhand des Spektrums sind ebenfalls die Peaks im Bereich des benötigten Frequenzbereichs zu sehen. Diese ordnen sich präzise zwischen den markierten Grenzfrequenzen von $5,0\,\text{MHz}$ und $6,0\,\text{MHz}$ ein, wobei sich das Nutzsignal bei etwa $-30\,\text{dBV}$ mit einem hohen Störabstand deutlich vom Grundrauschen abhebt. Die Kennlinie der Steuerspannung zu der Ausgangsfrequenz zeigt ebenfalls ein deutliches lineares Verhalten, wie bereits in der Simulation zu sehen. Der abgebildete Steuerbereich von $0\,\text{V}$ bis $1\,\text{V}$ deckt den geforderten Frequenzhub präzise ab, wobei die Kurve bei $0\,\text{V}$ exakt bei $5,0\,\text{MHz}$ startet und bei $1\,\text{V}$ den oberen Grenzwert von $6,0\,\text{MHz}$ erreicht

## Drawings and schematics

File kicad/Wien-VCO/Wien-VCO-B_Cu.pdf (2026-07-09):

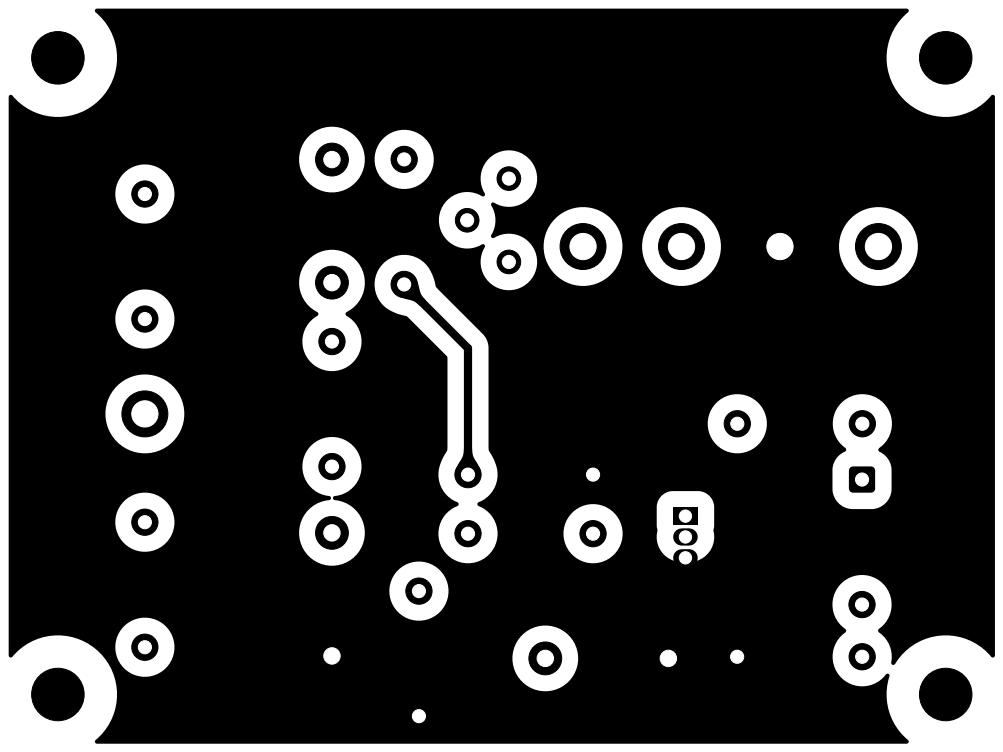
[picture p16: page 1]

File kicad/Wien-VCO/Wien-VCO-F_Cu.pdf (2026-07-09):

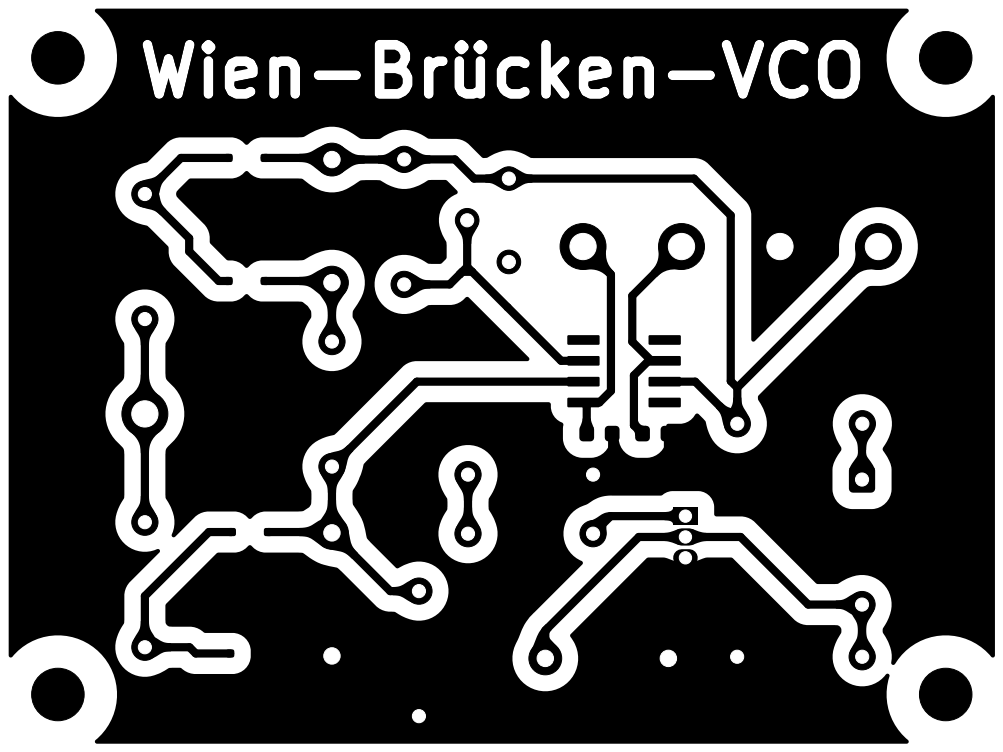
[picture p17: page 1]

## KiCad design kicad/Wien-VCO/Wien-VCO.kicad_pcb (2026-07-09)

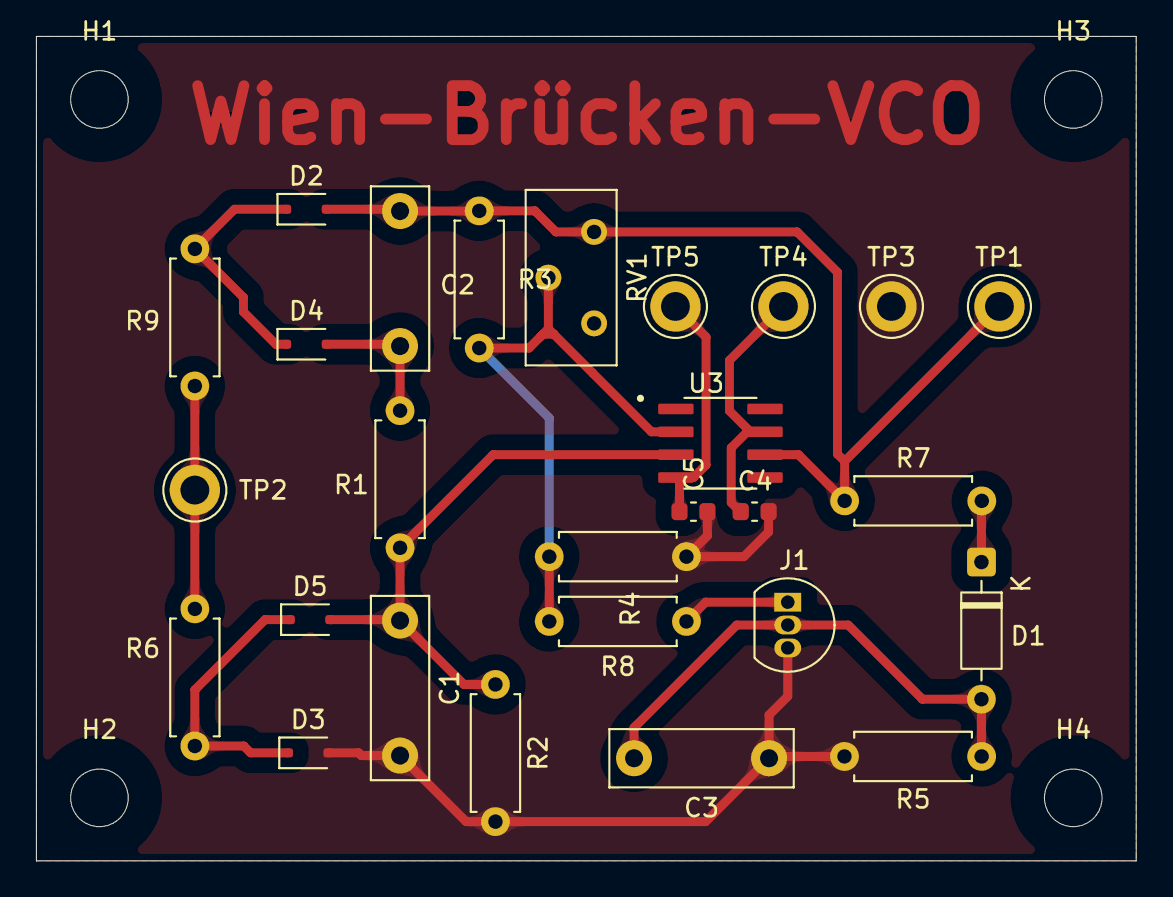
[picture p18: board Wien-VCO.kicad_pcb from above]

Board: 2 copper layers, 61.1 x 45.8 mm, 31 parts (0 on the bottom side), 14 nets.

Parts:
C1, C2: {C}; C_Rect_L10.0mm_W3.0mm_P7.50mm_MKS4
C3: 2nF; C_Rect_L10.0mm_W3.0mm_P7.50mm_MKS4
C4, C5: 100nF; C_0603_1608Metric
D1: 1N6263; D_DO-35_SOD27_P7.62mm_Horizontal
D2, D3, D4, D5: BB535/SIE; D_SOD-323F
H1, H2, H3, H4: MountingHole; MountingHole_3.2mm_M3_ISO7380
J1: J113; TO-92_Inline
R1, R2: {R}; R_Axial_DIN0207_L6.3mm_D2.5mm_P7.62mm_Horizontal
R3: 2K23; R_Axial_DIN0207_L6.3mm_D2.5mm_P7.62mm_Horizontal
R4: 1K2; R_Axial_DIN0207_L6.3mm_D2.5mm_P7.62mm_Horizontal
R5: 20K; R_Axial_DIN0207_L6.3mm_D2.5mm_P7.62mm_Horizontal
R6, R9: 100K; R_Axial_DIN0207_L6.3mm_D2.5mm_P7.62mm_Horizontal
R7: 1K; R_Axial_DIN0207_L6.3mm_D2.5mm_P7.62mm_Horizontal
R8: 8K; R_Axial_DIN0207_L6.3mm_D2.5mm_P7.62mm_Horizontal
RV1: R_Potentiometer; Potentiometer_Bourns_3296Y_Vertical
TP1, TP2, TP3, TP4, TP5: TestPoint; TestPoint_Keystone_5010-5014_Multipurpose
U3: MAX4104ESA_; SOIC127P600X175-8N_neu

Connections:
0: C1.2, C3.1, C4.1, C5.1, D3.2 (A), J1.3 (S), R2.2, R4.2, R5.2, TP3.1 (1_1)
unnamed: C3.2, D1.2 (A), J1.2 (G), R5.1
unnamed: D1.1 (K), R7.2
unnamed: D2.1 (K), D4.1 (K), R9.2
unnamed: D3.1 (K), D5.1 (K), R6.2
unnamed: C2.2, D4.2 (A), R1.1
unnamed: J1.1 (D), R8.2
unnamed: U3.1 (NC), U3.5 (NC), U3.8 (NC)
V2: C1.1, D5.2 (A), R1.2, R2.1, U3.3 (IN+)
VCC+: C4.2, TP4.1 (1_1), U3.7 (VCC)
VCC-: C5.2, TP5.1 (1_1), U3.4 (VEE)
Va: C2.1, D2.2 (A), R3.2, R7.1, RV1.3, TP1.1 (1_1), U3.6 (OUT)
Ve: R3.1, R4.1, R8.1, RV1.2, U3.2 (IN-)
Vstr: R6.1, R9.1, TP2.1 (1_1)

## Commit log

2026-04-16 Added report and kicad fm-vco
    [FM-Spannungsversorgung.kicad_sch, FM-Treiber.kicad_sch, FM-VCO.kicad_pcb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]
2026-04-16 KiCAD Projekt
    [Testprojekt.kicad_pcb, Testprojekt.kicad_sch]
2026-04-23 Update Kundenanforderungen
    [Untitled.kicad_pcb, Untitled.kicad_sch]
2026-04-23 Testprojekt Update
    [Testprojekt.kicad_pcb, Testprojekt.kicad_sch]
2026-05-07 Ordner Code für Python Auswertung hinzugefügt
    [Testprojekt.kicad_sch]
2026-05-07 Aufräumen die Zweite
    [Schwingkreis.kicad_pcb, Schwingkreis.kicad_sch, Testprojekt.kicad_pcb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]
2026-05-07 KiCad VCO-Schwingkreis Projekt Aktualisierung
    [VCO-Schwingkreis.kicad_pcb, VCO-Schwingkreis.kicad_sch]
2026-05-08 Anfang der Dokumentation
    [VCO-Schwingkreis.kicad_sch]
2026-05-16 Update des Reports
2026-05-20 Ordnung geschaffen
    [Schwingkreis.kicad_pcb, Schwingkreis.kicad_sch, Testprojekt.kicad_pcb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]
2026-05-21 Kapazitätsdiode eingebaut
    [VCO-Schwingkreis.kicad_sch]
2026-05-21 Wien-Brücken-Oszillator hinzugefügt
    [VCO-Schwingkreis.kicad_sch, Wien-VCO.kicad_pcb, Wien-VCO.kicad_sch]
2026-05-21 Wien-Brücken-Schwinger mit JFET zur Amplitudenstabilisierung
    [Wien-VCO.kicad_sch]
2026-06-04 Wien-Brpcken-Schwinger-Dioden hinzugefügt
    [Wien-VCO.kicad_pcb, Wien-VCO.kicad_sch]
2026-06-10 5.5 MHz Update
    [Wien-VCO.kicad_sch]
2026-06-10 Archiv erstellt
    [VCO-Schwingkreis.kicad_pcb, VCO-Schwingkreis.kicad_sch, Wien-VCO.kicad_pcb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]
2026-06-10 Pfade angepasst
    [Wien-VCO.kicad_sch]
2026-06-11 Update 5.5 MHz
    [Wien-VCO.kicad_sch]
2026-06-11 Erste Änderungen, Abgleiche LTspice vs ngspice
    [Wien-VCO.kicad_sch]
2026-06-12 Schaltung in LTSpice angepasst
    [Wien-VCO.kicad_sch]
2026-06-16 KiCAD und LTspice Modell MM
    [Wien-VCO_MM.kicad_sch]
2026-06-18 Added capometer for varactor diodes
2026-06-18 Varaktoren Änderung auf Linearität
    [Wien-VCO.kicad_pcb, Wien-VCO.kicad_sch, Wien-VCO_MM.kicad_sch]
2026-06-25 fix: Anpassung des .include Befehls
2026-06-26 Added BOM_Wien-LT
    [BOM_Wien-LT_TB.xlsx]
2026-06-29 BOM angepasst
    [BOM_Wien-LT_TB.xlsx, BOM_Wien-LT_TB_1.xlsx]
2026-06-29 Änderung auf neuen Varaktor
    [BOM_Wien-LT_TB.xlsx, BOM_Wien-LT_TB_1.xlsx]
2026-07-02 Kicad Schaltplan
    [1N6263.STEP, 1N6263.step, J113.STEP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]
2026-07-02 Ordnerstruktur angepasst
    [BOM_Wien-LT_TB.xlsx, FM-Spannungsversorgung.kicad_sch, FM-Treiber.kicad_sch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]
2026-07-02 sim Ordner angepasst
    [Wien-VCO.kicad_sch]
2026-07-02 Update Ordnerstruktur
    [1N6263.step, BOM_Wien-LT_TB.xlsx, J113.step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]
2026-07-06 Layout erstellt
    [BOM_Wien-LT_TB.xlsx, BOM_Wien-VCO.xlsx, Wien-VCO.kicad_pcb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]
2026-07-06 Layout angepasst
    [Wien-VCO.kicad_pcb, Wien-VCO.kicad_sch]
2026-07-09 Layout finalisiert
    [Wien-VCO.kicad_pcb, Wien-VCO.kicad_sch]
2026-07-10 Kennlinien Plot
    [20260709_01.csv, 20260709_02.csv, 20260709_03.csv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]
2026-07-17 Umsortierung/ Aufgeräumt & Bericht
    [20260709_01.csv, 20260709_02.csv, 20260709_03.csv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]
2026-07-19 Document component value adjustments in README
    Added a table summarizing component adjustments due to parasitic properties of the measurement setup and PCB layout.
